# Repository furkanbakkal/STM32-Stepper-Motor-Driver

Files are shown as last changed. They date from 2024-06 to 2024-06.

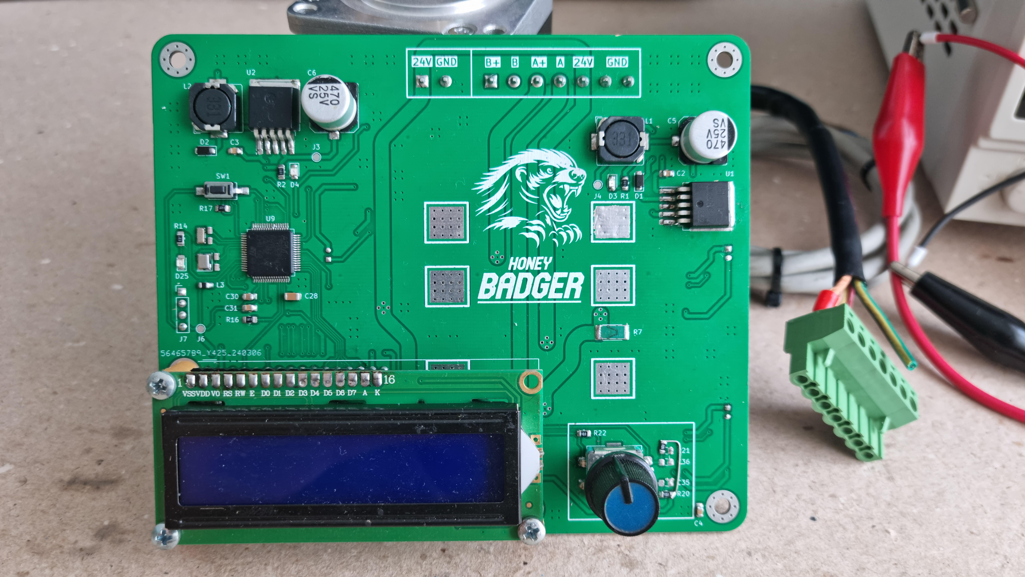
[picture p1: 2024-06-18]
render/reel-top-min.jpg

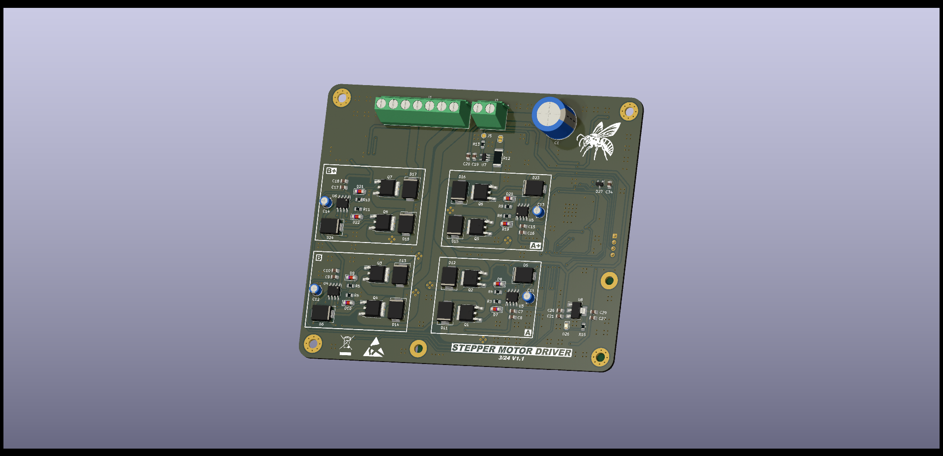
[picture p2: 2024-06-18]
render/back.png

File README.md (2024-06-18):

STM32-Stepper-Motor-Driver

-Hi! This project for Istanbul University Cerrahpaşa Electrical and Electronics Engineering graduation. 

-This is "STM32 and N-MOS Based Stepper Motor Driver"

- 2 layer PCB
- Full stepper motor control circuit

## Features

- Microstepping up to 1/258
- Very quiet and vibration-free step motor driving
- Current limiting
- High current support (up to 8A)
- Speed control (up to 10KHz pulse)
- Motor direction control (CW, CCW)

## Tech

- STM32F401RBT6
- IR2104 MOS gate driver

## Photos

reel-top-min
reel-back-min




back
top

Note: Cable jumps on the board have been fixed in version 1.2

## Demo

You can check this Google Drive link for real life demo: https://drive.google.com/file/d/10obyRq6SgMOz6bZmb6Qkc-JsMecKdY-S/view?usp=sharing



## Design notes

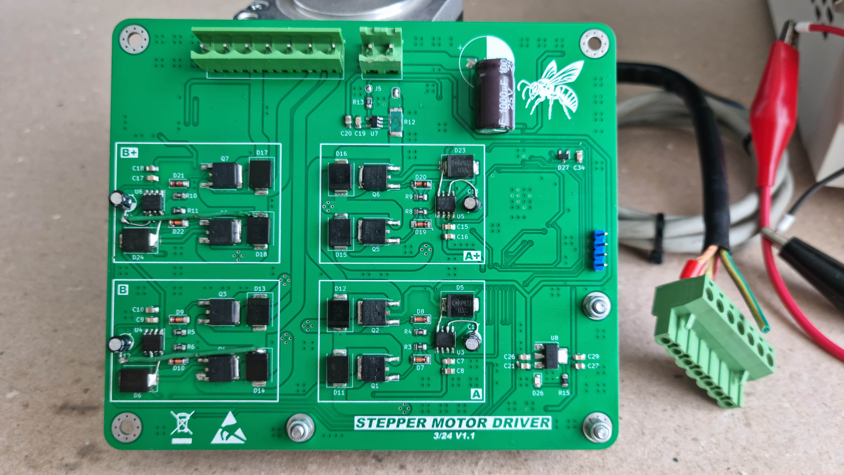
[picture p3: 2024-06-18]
render/reel-back-min.jpg

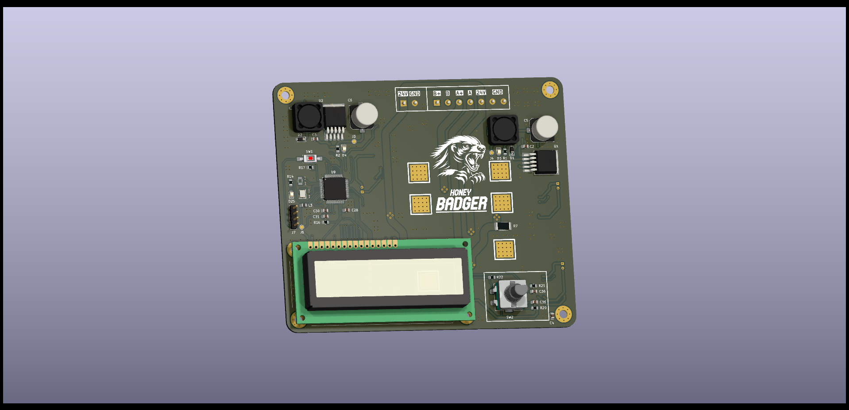
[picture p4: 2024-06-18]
render/top.png

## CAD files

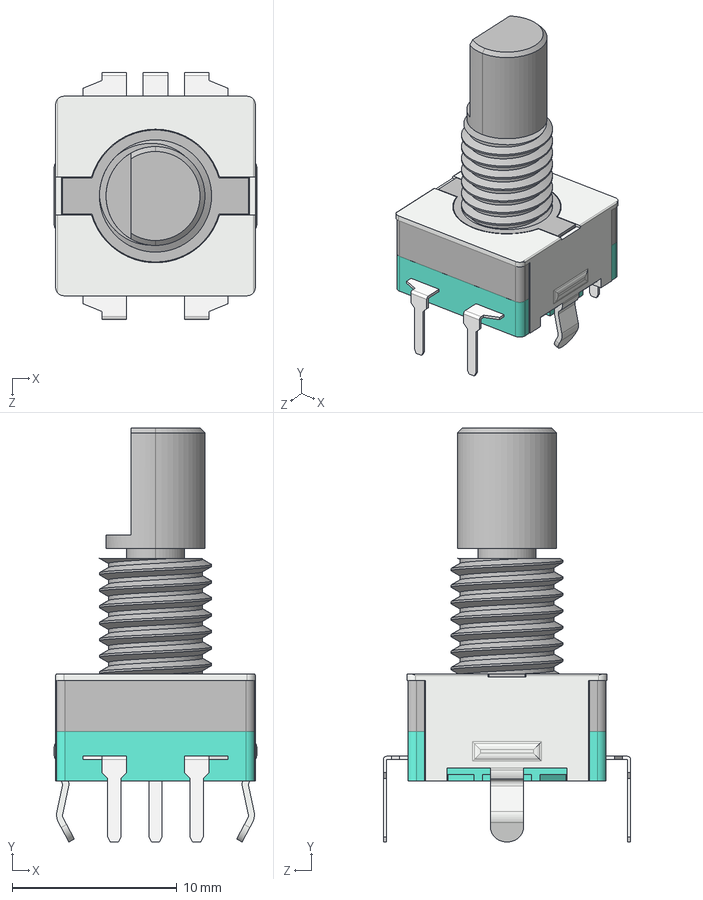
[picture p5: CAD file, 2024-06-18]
original-stepper-driver/external-3d-models/encoder.step
12.3 x 25.1 x 15.0 mm

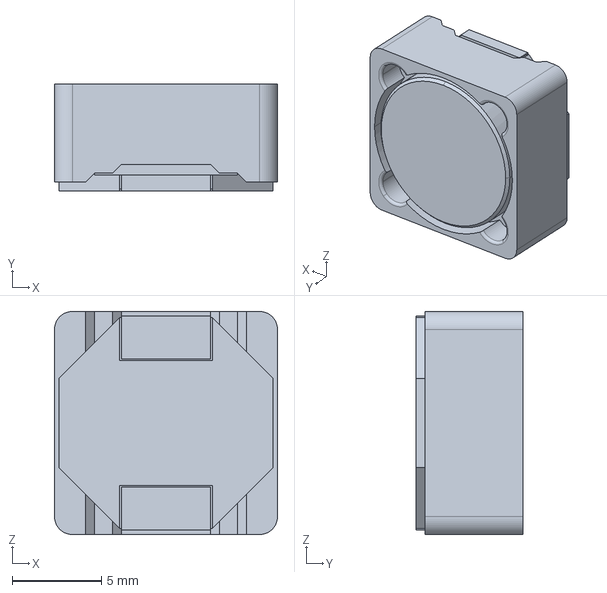
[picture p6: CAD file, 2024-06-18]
original-stepper-driver/external-3d-models/SRR1260-330M.step
12.5 x 6.00 x 12.5 mm

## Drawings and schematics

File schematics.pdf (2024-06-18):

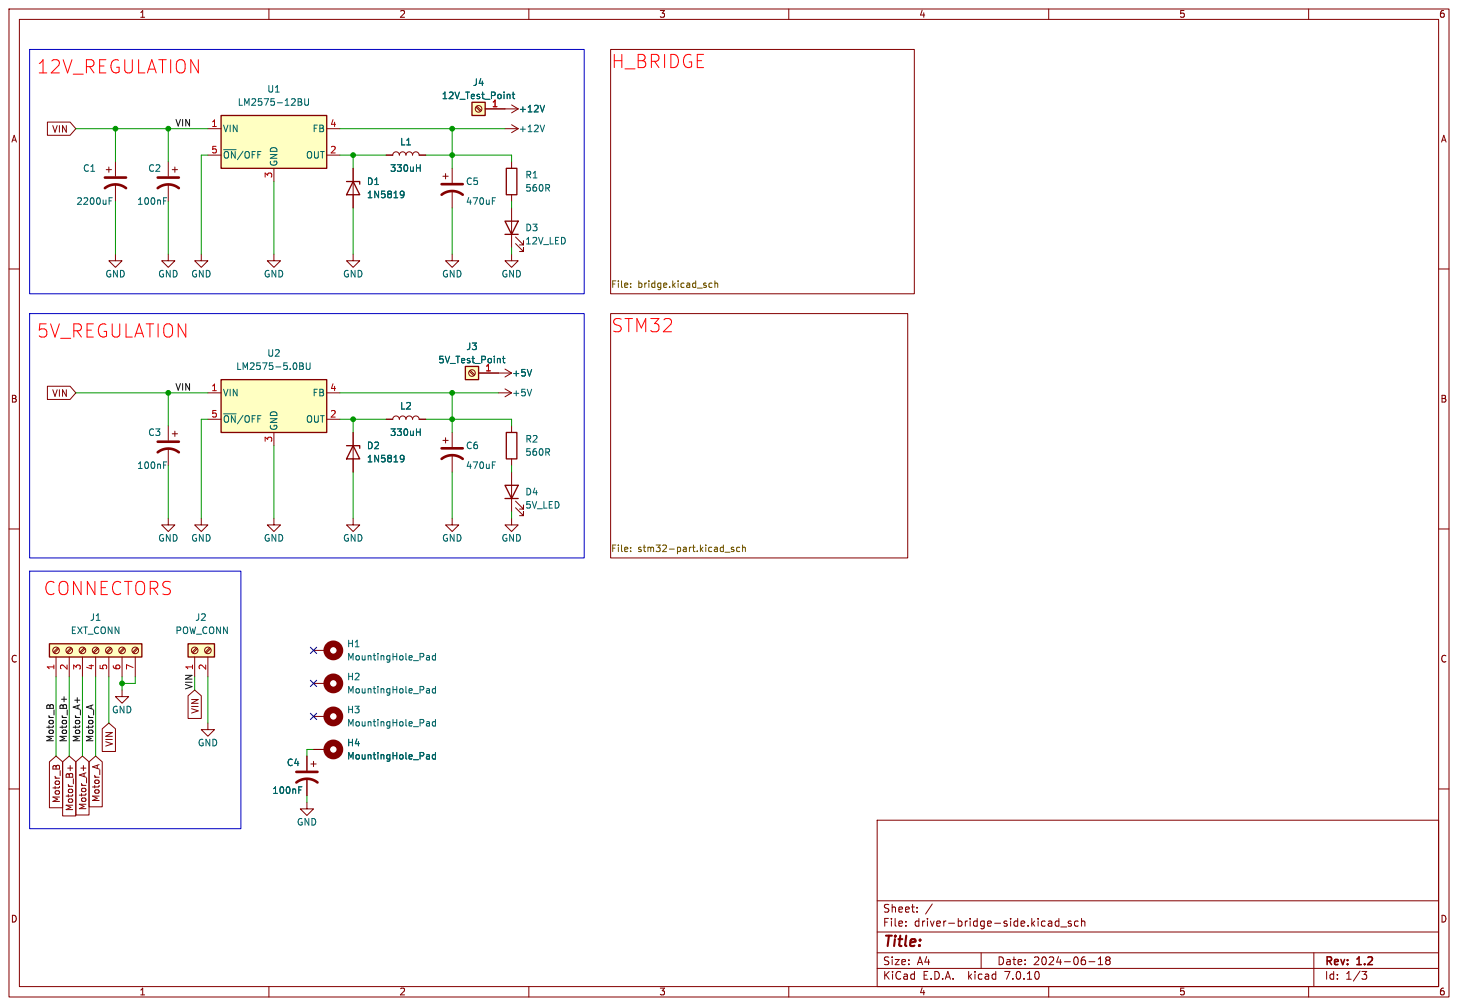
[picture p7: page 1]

Id: 1/3 Title: File: driver-bridge-side.kicad_sch Sheet: / H_BRIDGE

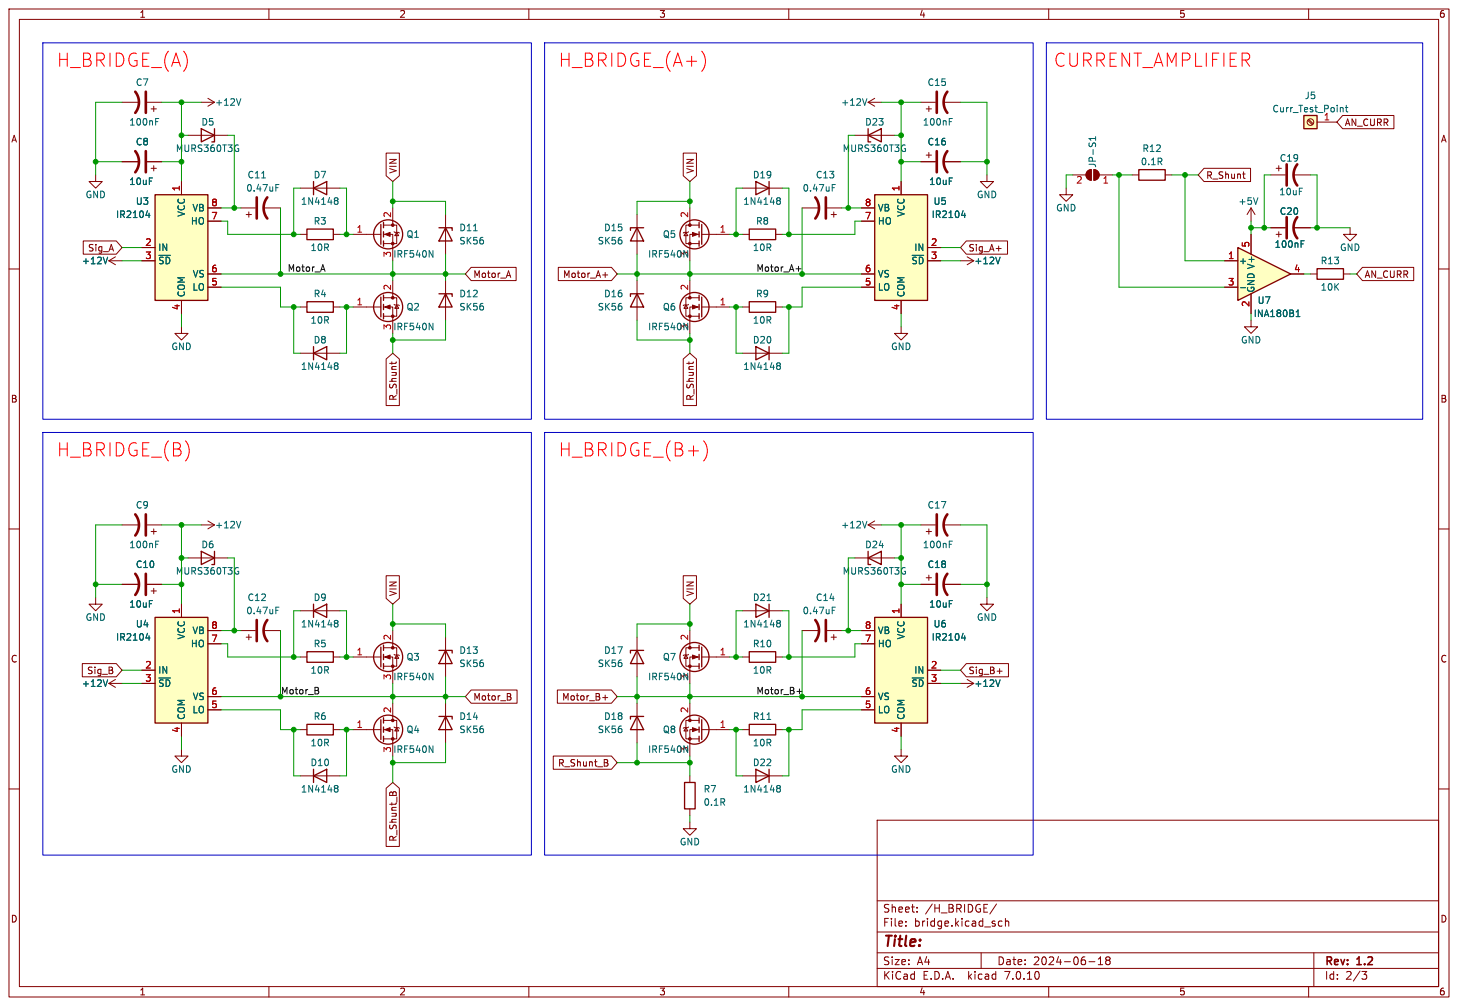
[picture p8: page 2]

Id: 2/3 Title: File: bridge.kicad_sch Sheet: /H_BRIDGE/

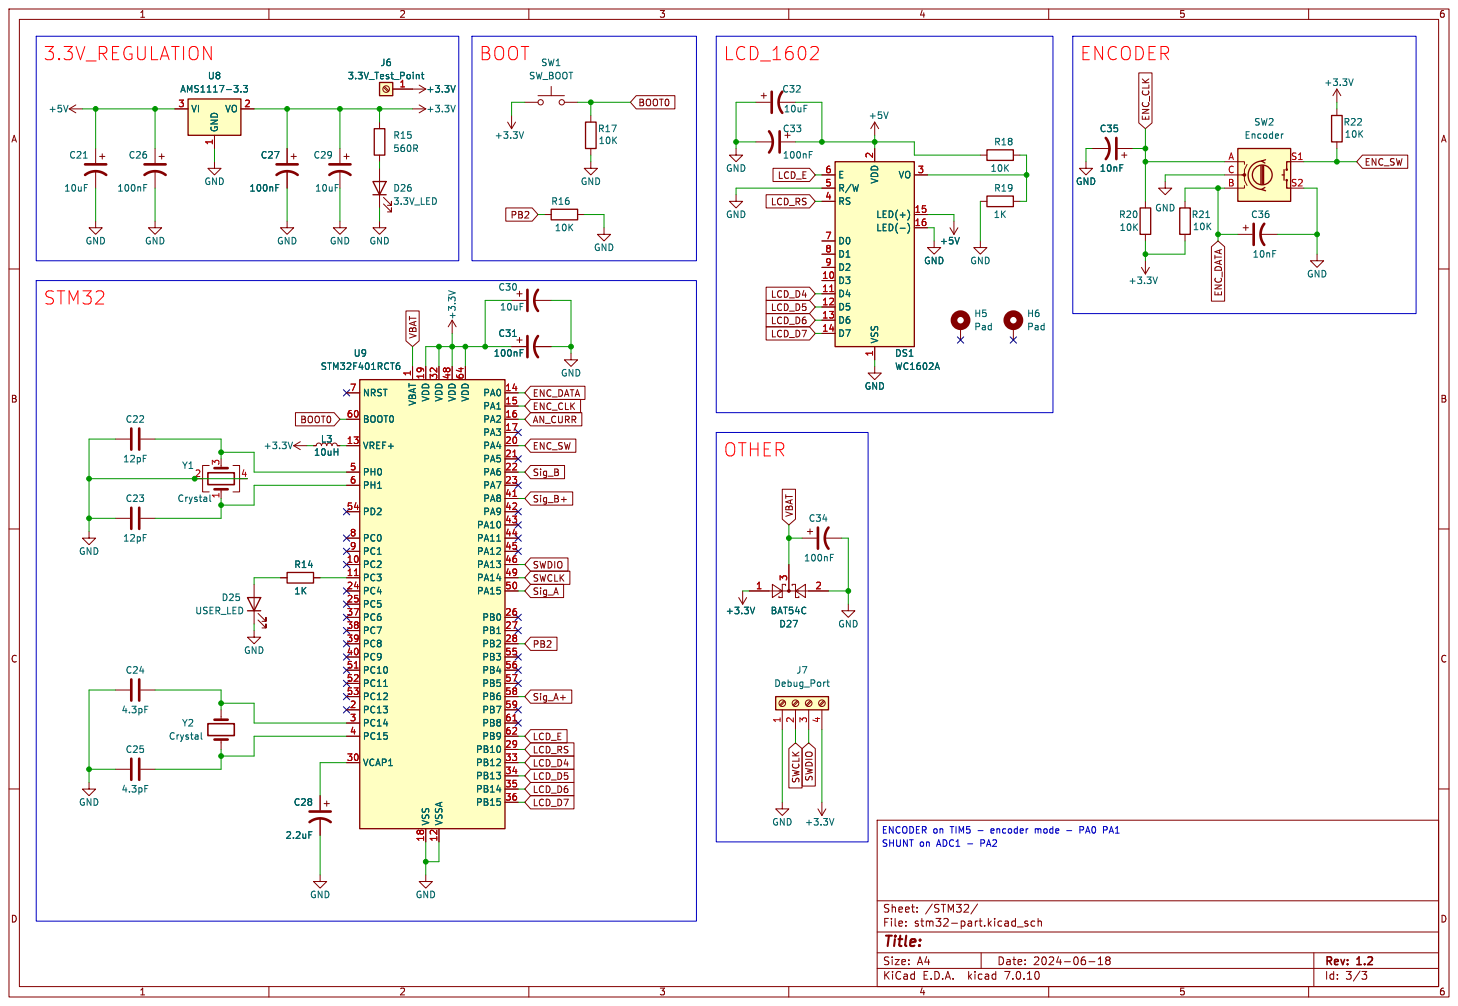
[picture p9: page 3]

1 PC2 10 PC3 11 VSSA 12 VREF+ 13 PA0 14 PA1 15 PA2 16 PA3 17 VSS 18 VDD 19 PC13 2 PA4 20 PA5 21 PA6 22 PA7 23 PC4 24 PC5 25 PB0 26 PB1 27 PB2 28 PB10 29 PC14 3 VCAP1 30 VDD 32 PB12 33 PB13 34 PB14 35 PB15 36 PC6 37 PC7 38 PC8 39 PC15 4 PC9 40 PA8 41 PA9 42 PA10 43 PA11 44 PA12 45 PA13 46 VDD 48 PA14 49 PH0 5 PA15 50 PC10 51 PC11 52 PC12 53 PD2 54 PB3 55 PB4 56 PB5 57 PB6 58 PB7 59 PH1 6 BOOT0 60 PB8 61 PB9 62 VDD 64 NRST 7 PC0 8 PC1 9U9 STM32F401RCT6 GND

1 PC2 10 PC3 11 VSSA 12 VREF+ 13 PA0 14 PA1 15 PA2 16 PA3 17 VSS 18 VDD 19 PC13 2 PA4 20 PA5 21 PA6 22 PA7 23 PC4 24 PC5 25 PB0 26 PB1 27 PB2 28 PB10 29 PC14 3 VCAP1 30 VDD 32 PB12 33 PB13 34 PB14 35 PB15 36 PC6 37 PC7 38 PC8 39 PC15 4 PC9 40 PA8 41 PA9 42 PA10 43 PA11 44 PA12 45 PA13 46 VDD 48 PA14 49 PH0 5 PA15 50 PC10 51 PC11 52 PC12 53 PD2 54 PB3 55 PB4 56 PB5 57 PB6 58 PB7 59 PH1 6 BOOT0 60 PB8 61 PB9 62 VDD 64 NRST 7 PC0 8 PC1 9 C28

ENCODER on TIM5 - encoder mode - PA0 PA1

Id: 3/3 Title: File: stm32-part.kicad_sch Sheet: /STM32/

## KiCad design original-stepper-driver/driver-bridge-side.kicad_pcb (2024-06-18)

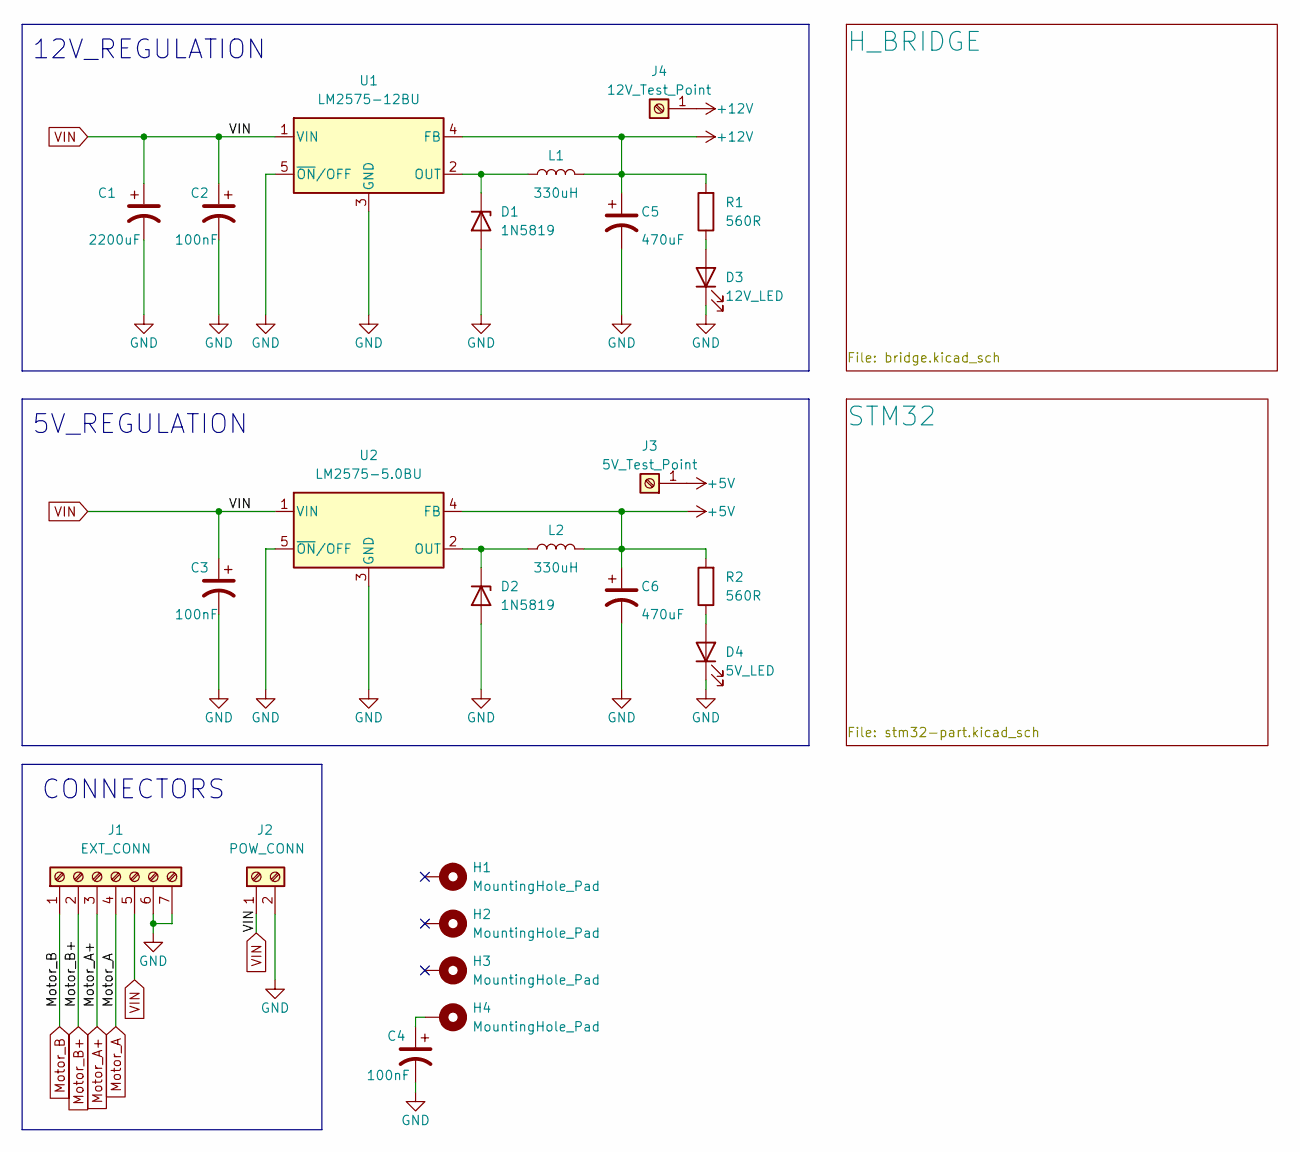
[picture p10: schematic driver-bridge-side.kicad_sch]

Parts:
C1: 2200uF; CP_Radial_D14.0mm_P7.50mm
C2, C3, C4: 100nF; C_0805_2012Metric_Pad1.18x1.45mm_HandSolder
C5, C6: 470uF; C_Elec_10x10.2
D1, D2: 1N5819; D_SOD-123
D3: 12V_LED; LED_0805_2012Metric_Pad1.15x1.40mm_HandSolder
D4: 5V_LED; LED_0805_2012Metric_Pad1.15x1.40mm_HandSolder
H1, H2, H3, H4: MountingHole_Pad; MountingHole_3.7mm_Pad_Via
J1: EXT_CONN; TerminalBlock_Phoenix_MKDS-1,5-7_1x07_P5.00mm_Horizontal
J2: POW_CONN; TerminalBlock_Phoenix_MKDS-1,5-2-5.08_1x02_P5.08mm_Horizont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
J3: 5V_Test_Point; TestPoint_Pad_D1.5mm
J4: 12V_Test_Point; TestPoint_Pad_D1.5mm
L1, L2: 330uH; L_Bourns_SRP1038C_10.0x10.0mm
R1, R2: 560R; R_0805_2012Metric_Pad1.20x1.40mm_HandSolder
U1: LM2575-12BU; TO-263-5_TabPin3
U2: LM2575-5.0BU; TO-263-5_TabPin3

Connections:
+5V: C6.1, J3.1, L2.2, R2.2, U2.4 (FB); also elsewhere on the board
+12V: C5.1, J4.1, L1.2, R1.2, U1.4 (FB); also elsewhere on the board
GND: C1.2, C2.2, C3.2, C4.2, C5.2, C6.2, D1.2 (A), D2.2 (A), D3.1 (K), D4.1 (K), J1.6, J1.7, J2.2, U1.3 (GND), U1.5 (~ON/OFF), U2.3 (GND), U2.5 (~ON/OFF); also elsewhere on the board
Motor_A: J1.4; also elsewhere on the board
Motor_A+: J1.3; also elsewhere on the board
Motor_B: J1.1; also elsewhere on the board
Motor_B+: J1.2; also elsewhere on the board
unnamed: C4.1, H4.1
unnamed: D1.1 (K), L1.1, U1.2 (OUT)
unnamed: D2.1 (K), L2.1, U2.2 (OUT)
unnamed: D3.2 (A), R1.1
unnamed: D4.2 (A), R2.1
VIN: C1.1, C2.1, C3.1, J1.5, J2.1, U1.1 (VIN), U2.1 (VIN); also elsewhere on the board

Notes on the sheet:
12V_REGULATION
5V_REGULATION
CONNECTORS

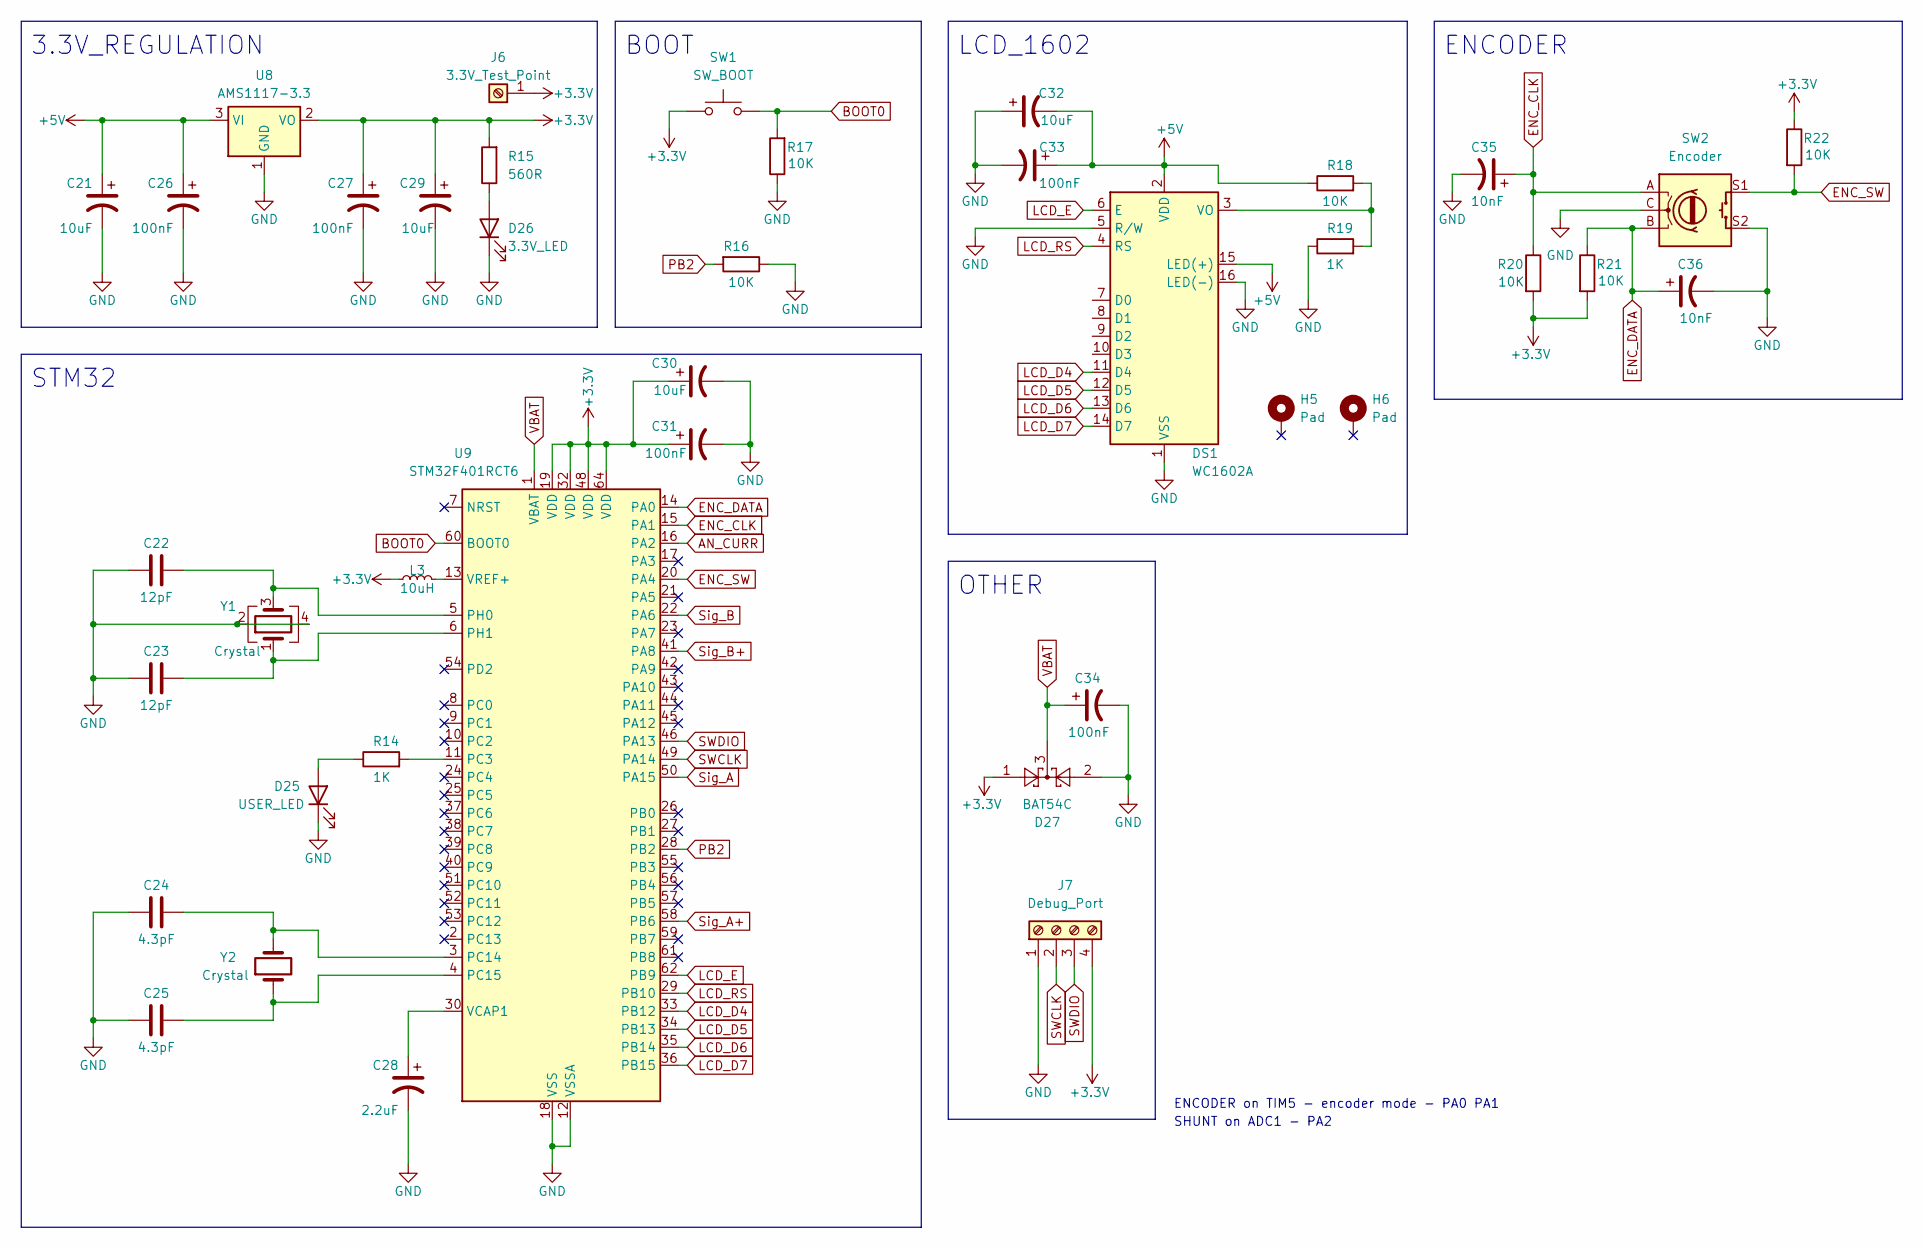
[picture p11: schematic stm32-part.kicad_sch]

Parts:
C21, C29, C30, C32: 10uF; C_0805_2012Metric_Pad1.18x1.45mm_HandSolder
C22, C23: 12pF; C_0201_0603Metric_Pad0.64x0.40mm_HandSolder
C24, C25: 4.3pF; C_0201_0603Metric_Pad0.64x0.40mm_HandSolder
C26, C27, C31, C33, C34: 100nF; C_0805_2012Metric_Pad1.18x1.45mm_HandSolder
C28: 2.2uF; C_0805_2012Metric_Pad1.18x1.45mm_HandSolder
C35, C36: 10nF; C_0805_2012Metric_Pad1.18x1.45mm_HandSolder
D25: USER_LED; LED_0805_2012Metric_Pad1.15x1.40mm_HandSolder
D26: 3.3V_LED; LED_0805_2012Metric_Pad1.15x1.40mm_HandSolder
D27: BAT54C; SOT-23
DS1: WC1602A
H5, H6: Pad; MountingHole_3.5mm_Pad
J6: 3.3V_Test_Point; TestPoint_Pad_D1.5mm
J7: Debug_Port; PinHeader_1x04_P2.54mm_Vertical
L3: 10uH; L_0805_2012Metric_Pad1.05x1.20mm_HandSolder
R14, R19: 1K; R_0805_2012Metric_Pad1.20x1.40mm_HandSolder
R15: 560R; R_0805_2012Metric_Pad1.20x1.40mm_HandSolder
R16, R17, R18, R20, R21, R22: 10K; R_0805_2012Metric_Pad1.20x1.40mm_HandSolder
SW1: SW_BOOT; SW_SPST_FSMSM
SW2: Encoder; RotaryEncoder_Alps_EC11E-Switch_Vertical_H20mm_NoChasis
U8: AMS1117-3.3; SOT-223-3_TabPin2
U9: STM32F401RCT6; LQFP-64_10x10mm_P0.5mm
Y1: Crystal; Crystal_SMD_3225-4Pin_3.2x2.5mm
Y2: Crystal; Crystal_SMD_3215-2Pin_3.2x1.5mm

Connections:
+3.3V: C27.1, C29.1, C30.1, C31.1, D27.1, J6.1, J7.4, L3.1, R15.2, R20.2, R21.2, R22.1, SW1.1, U8.2 (VO), U9.19 (VDD), U9.32 (VDD), U9.48 (VDD), U9.64 (VDD)
+5V: C21.1, C26.1, C32.2, C33.1, DS1.2 (VDD), DS1.15 (LED(+)), R18.1, U8.3 (VI); also elsewhere on the board
AN_CURR: U9.16 (PA2); also elsewhere on the board
BOOT0: R17.2, SW1.2, U9.60 (BOOT0)
ENC_CLK: C35.1, R20.1, SW2.A, U9.15 (PA1)
ENC_DATA: C36.1, R21.1, SW2.B, U9.14 (PA0)
ENC_SW: R22.2, SW2.S1, U9.20 (PA4)
GND: C21.2, C22.2, C23.1, C24.2, C25.1, C26.2, C27.2, C28.2, C29.2, C30.2, C31.2, C32.1, C33.2, C34.2, C35.2, C36.2, D25.1 (K), D26.1 (K), D27.2, DS1.1 (VSS), DS1.5 (R/W), DS1.16 (LED(-)), J7.1, R16.1, R17.1, R19.1, SW2.C, SW2.S2, U8.1 (GND), U9.12 (VSSA), U9.18 (VSS), U9.31 (VSS), U9.47 (VSS), U9.63 (VSS), Y1.2, Y1.4; also elsewhere on the board
LCD_D4: DS1.11 (D4), U9.33 (PB12)
LCD_D5: DS1.12 (D5), U9.34 (PB13)
LCD_D6: DS1.13 (D6), U9.35 (PB14)
LCD_D7: DS1.14 (D7), U9.36 (PB15)
LCD_E: DS1.6 (E), U9.62 (PB9)
LCD_RS: DS1.4 (RS), U9.29 (PB10)
unnamed: D25.2 (A), R14.1
unnamed: D26.2 (A), R15.1
unnamed: DS1.3 (VO), R18.2, R19.2
unnamed: R14.2, U9.11 (PC3)
unnamed: C24.1, U9.3 (PC14), Y2.2
unnamed: C25.2, U9.4 (PC15), Y2.1
unnamed: C22.1, U9.5 (PH0), Y1.3
unnamed: C23.2, U9.6 (PH1), Y1.1
unnamed: C28.1, U9.30 (VCAP1)
unnamed: L3.2, U9.13 (VREF+)
PB2: R16.2, U9.28 (PB2)
SWCLK: J7.2, U9.49 (PA14)
SWDIO: J7.3, U9.46 (PA13)
Sig_A: U9.50 (PA15); also elsewhere on the board
Sig_A+: U9.58 (PB6); also elsewhere on the board
Sig_B: U9.22 (PA6); also elsewhere on the board
Sig_B+: U9.41 (PA8); also elsewhere on the board
VBAT: C34.1, D27.3, U9.1 (VBAT)

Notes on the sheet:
STM32
LCD_1602
OTHER
BOOT
ENCODER on TIM5 - encoder mode - PA0 PA1
3.3V_REGULATION
SHUNT on ADC1 - PA2
ENCODER

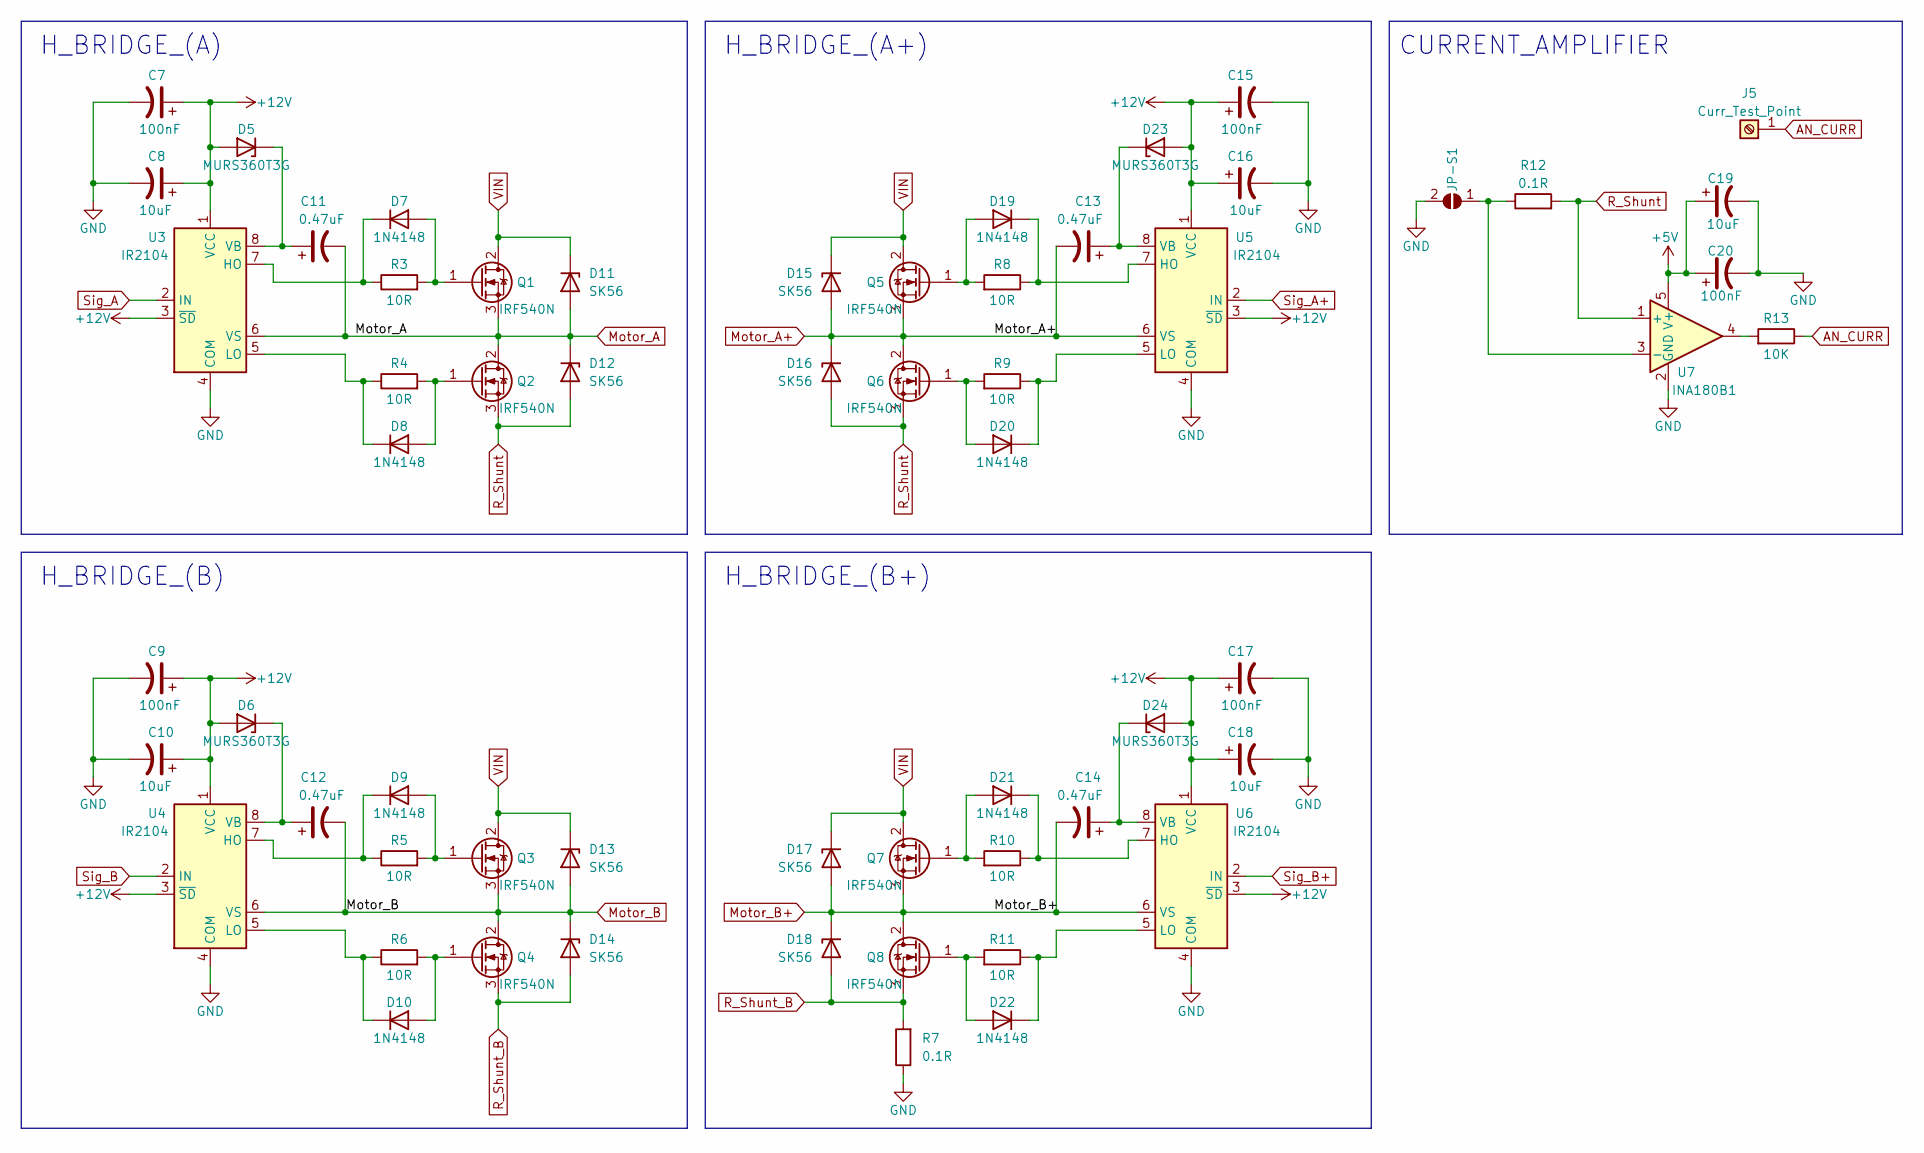
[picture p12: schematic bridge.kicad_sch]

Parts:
C7, C9, C15, C17, C20: 100nF; C_0805_2012Metric_Pad1.18x1.45mm_HandSolder
C8, C10, C16, C18, C19: 10uF; C_0805_2012Metric_Pad1.18x1.45mm_HandSolder
C11, C12, C13, C14: 0.47uF; CP_Radial_D4.0mm_P2.00mm
D5, D6, D23, D24: MURS360T3G; D_SMC
D7, D8, D9, D10, D19, D20, D21, D22: 1N4148; D_MiniMELF
D11, D12, D13, D14, D15, D16, D17, D18: SK56; D_SMC
J5: Curr_Test_Point; TestPoint_Pad_D1.5mm
JP-S1: SolderJumper_2_Open; SolderJumper-2_P1.3mm_Open_RoundedPad1.0x1.5mm
Q1, Q2, Q3, Q4, Q5, Q6, Q7, Q8: IRF540N; TO-252-2
R3, R4, R5, R6, R8, R9, R10, R11: 10R; R_0805_2012Metric_Pad1.20x1.40mm_HandSolder
R7, R12: 0.1R; R_2512_6332Metric_Pad1.40x3.35mm_HandSolder
R13: 10K; R_0805_2012Metric_Pad1.20x1.40mm_HandSolder
U3, U4, U5, U6: IR2104; SOIC-8_3.9x4.9mm_P1.27mm
U7: INA180B1; SOT-23-5_HandSoldering

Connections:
+5V: C19.1, C20.1, U7.5 (V+); also elsewhere on the board
+12V: C7.1, C8.1, C9.1, C10.1, C15.1, C16.1, C17.1, C18.1, D5.2 (A), D6.2 (A), D23.2 (A), D24.2 (A), U3.1 (VCC), U3.3 (~SD), U4.1 (VCC), U4.3 (~SD), U5.1 (VCC), U5.3 (~SD), U6.1 (VCC), U6.3 (~SD); also elsewhere on the board
AN_CURR: J5.1, R13.1; also elsewhere on the board
GND: C7.2, C8.2, C9.2, C10.2, C15.2, C16.2, C17.2, C18.2, C19.2, C20.2, JP-S1.2 (B), R7.1, U3.4 (COM), U4.4 (COM), U5.4 (COM), U6.4 (COM), U7.2 (GND); also elsewhere on the board
Motor_A: C11.2, D11.2 (A), D12.1 (K), Q1.3 (S), Q2.2 (D), U3.6 (VS); also elsewhere on the board
Motor_A+: C13.2, D15.2 (A), D16.1 (K), Q5.3 (S), Q6.2 (D), U5.6 (VS); also elsewhere on the board
Motor_B: C12.2, D13.2 (A), D14.1 (K), Q3.3 (S), Q4.2 (D), U4.6 (VS); also elsewhere on the board
Motor_B+: C14.2, D17.2 (A), D18.1 (K), Q7.3 (S), Q8.2 (D), U6.6 (VS); also elsewhere on the board
unnamed: C11.1, D5.1 (K), U3.8 (VB)
unnamed: C12.1, D6.1 (K), U4.8 (VB)
unnamed: D7.2 (A), Q1.1 (G), R3.2
unnamed: D7.1 (K), R3.1, U3.7 (HO)
unnamed: D8.2 (A), Q2.1 (G), R4.2
unnamed: D8.1 (K), R4.1, U3.5 (LO)
unnamed: D9.2 (A), Q3.1 (G), R5.2
unnamed: D9.1 (K), R5.1, U4.7 (HO)
unnamed: D10.2 (A), Q4.1 (G), R6.2
unnamed: D10.1 (K), R6.1, U4.5 (LO)
unnamed: D19.2 (A), Q5.1 (G), R8.2
unnamed: D19.1 (K), R8.1, U5.7 (HO)
unnamed: D20.2 (A), Q6.1 (G), R9.2
unnamed: D20.1 (K), R9.1, U5.5 (LO)
unnamed: D21.2 (A), Q7.1 (G), R10.2
unnamed: D21.1 (K), R10.1, U6.7 (HO)
unnamed: D22.2 (A), Q8.1 (G), R11.2
unnamed: D22.1 (K), R11.1, U6.5 (LO)
unnamed: C13.1, D23.1 (K), U5.8 (VB)
unnamed: C14.1, D24.1 (K), U6.8 (VB)
unnamed: JP-S1.1 (A), R12.1, U7.3 (-)
unnamed: R13.2, U7.4
R_Shunt: D12.2 (A), D16.2 (A), Q2.3 (S), Q6.3 (S), R12.2, U7.1 (+)
R_Shunt_B: D14.2 (A), D18.2 (A), Q4.3 (S), Q8.3 (S), R7.2
Sig_A: U3.2 (IN); also elsewhere on the board
Sig_A+: U5.2 (IN); also elsewhere on the board
Sig_B: U4.2 (IN); also elsewhere on the board
Sig_B+: U6.2 (IN); also elsewhere on the board
VIN: D11.1 (K), D13.1 (K), D15.1 (K), D17.1 (K), Q1.2 (D), Q3.2 (D), Q5.2 (D), Q7.2 (D); also elsewhere on the board

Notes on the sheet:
H_BRIDGE_(B)
H_BRIDGE_(A+)
H_BRIDGE_(A)
H_BRIDGE_(B+)
CURRENT_AMPLIFIER

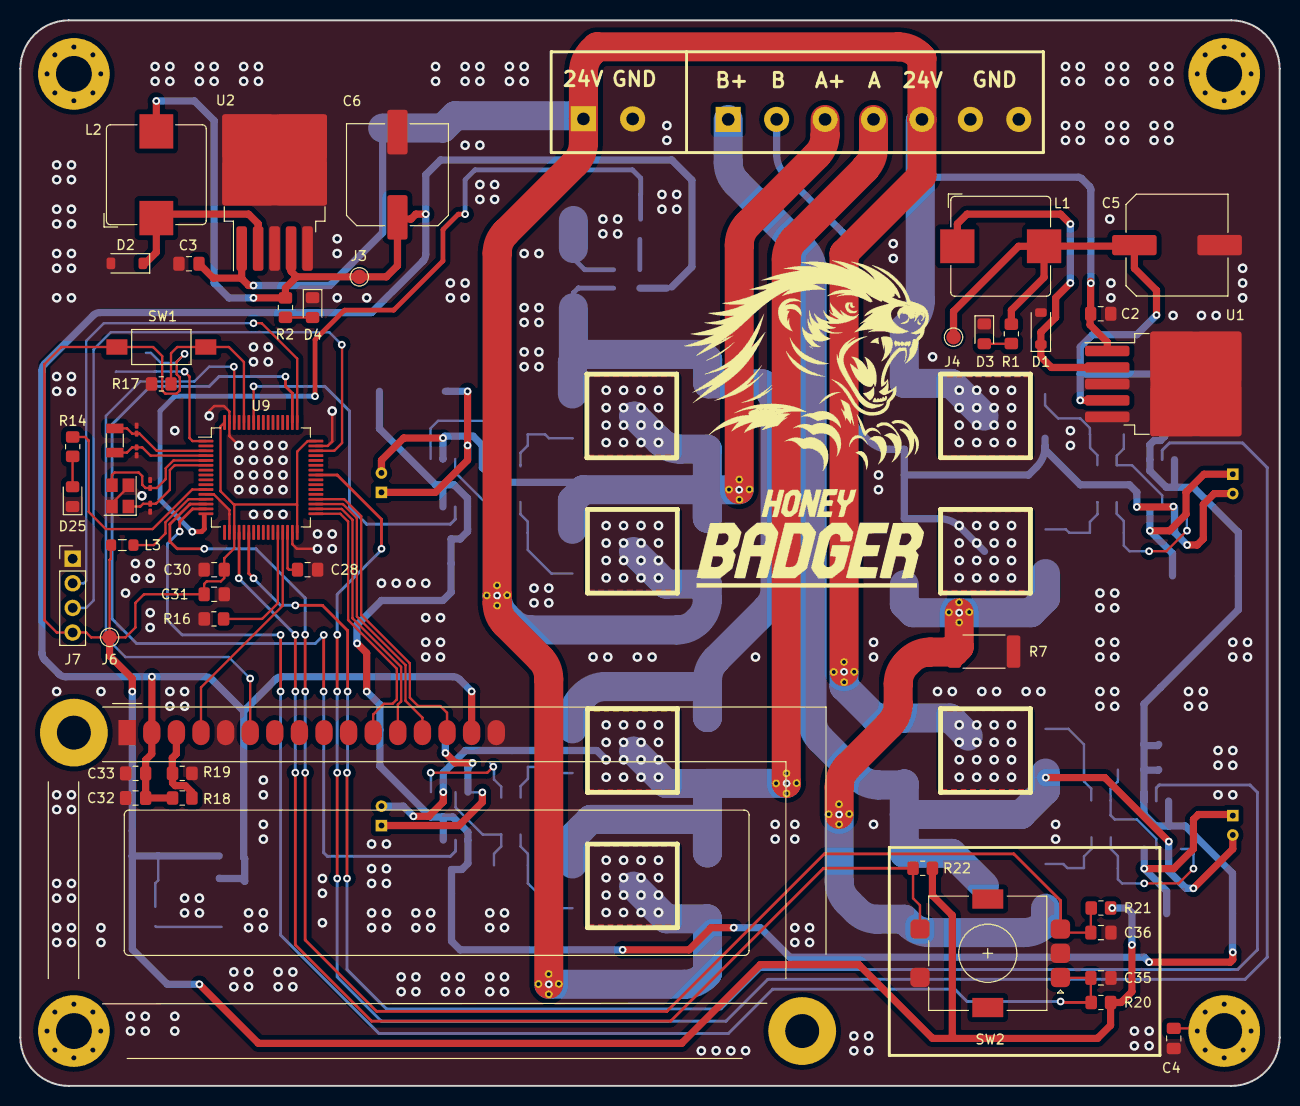
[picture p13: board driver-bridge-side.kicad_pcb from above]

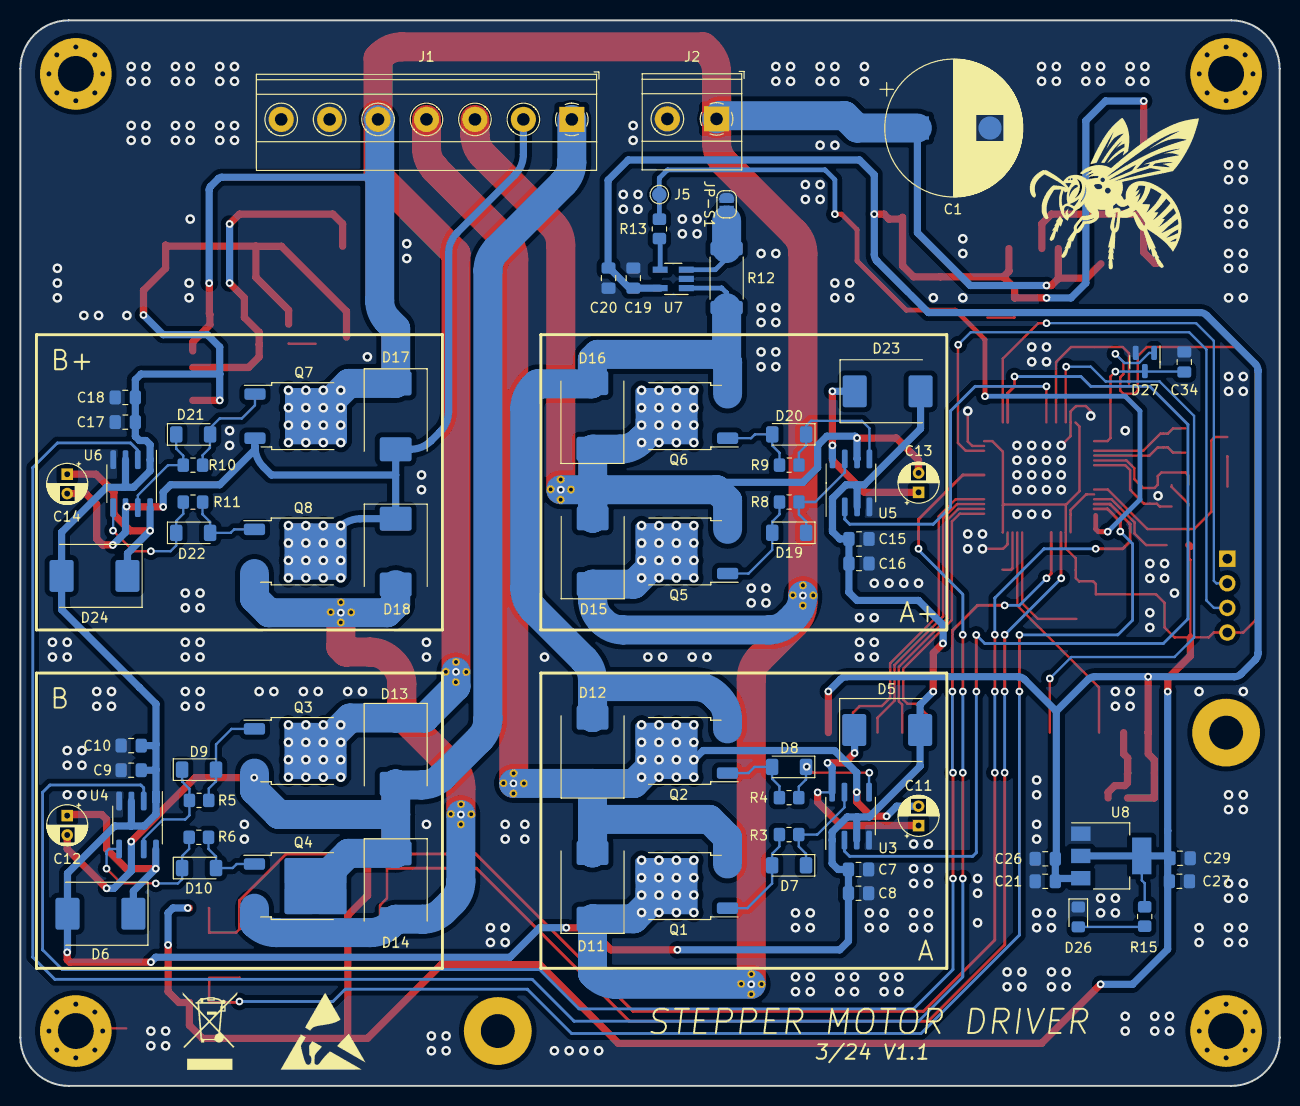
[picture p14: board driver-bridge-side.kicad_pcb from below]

Board: 2 copper layers, 130.0 x 110.0 mm, 128 parts (71 on the bottom side), 67 nets.

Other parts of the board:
V: (no value)
V#2, V#3, V#4: (no value)

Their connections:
Motor_A: V.1, V#2.1, V#3.1, V#4.1; also elsewhere on the board

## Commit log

2024-06-18 gerber file
    [driver-bridge-side-B_Cu.gbr, driver-bridge-side-B_Mask.gbr, driver-bridge-side-B_Paste.gbr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]
2024-06-18 kicad files
    [SRR1260-330M.step, bridge.kicad_sch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]
2024-06-18 STM32 codes
2024-06-18 schematic as PDF
2024-06-18 PCB layout and 3D render
2024-06-28 stm32 code
